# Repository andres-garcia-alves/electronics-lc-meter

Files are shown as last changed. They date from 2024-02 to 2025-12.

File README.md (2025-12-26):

# LC Meter v2.0

A Capacimeter + Inductometer based on Arduino Nano.  
Capacitor measurement with 3 working modes: accuracy (slow), balanced and speed.  

Case 3D model included ;-)

This proyect was inspired on video [Medidor de Bobinas/Inductores y Capacitores con Arduino y Display LCD](https://www.youtube.com/watch?v=hMa-AWyuxaA) (spanish) from [Electgpl](https://www.youtube.com/@electgpl) YouTube channel.

&nbsp;

This project use the following electronic components:
- 1 x Arduino Nano v3.0
- 1 x LCD Display 16x2
- 1 x LCD Display I2C Module
- 1 x LM358 Operational Amplifier
- 1 x Capacitor 1uF
- 1 x Switch Button (2 positions)
- 3 x Push Button
- 1 x 220 ohm resistor
- 1 x 470 ohm resistor
- 1 x 10K ohm resistor
- 1 x 100K ohm resistor
- 1 x 1M ohm resistor
- 14 x pin-header 90 degress
- 2 x Bornier x2 (optional)
- 1 x DC conector (optional power 5-12V)
- 2 x Alligator clip conector (optional external measurement)
- wires

&nbsp;

### Screenshots

| Diagram - Schematics | Diagram - PCB |
|---|---|
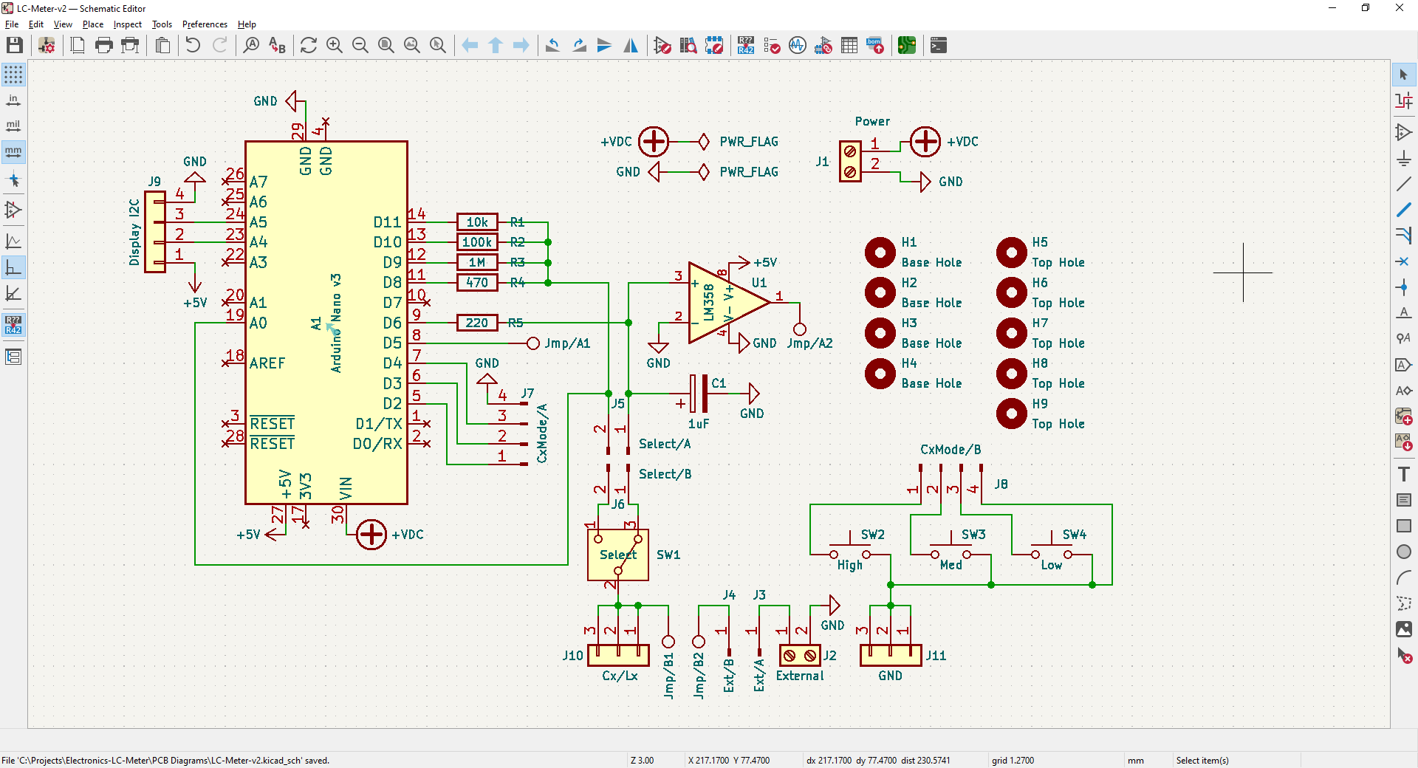
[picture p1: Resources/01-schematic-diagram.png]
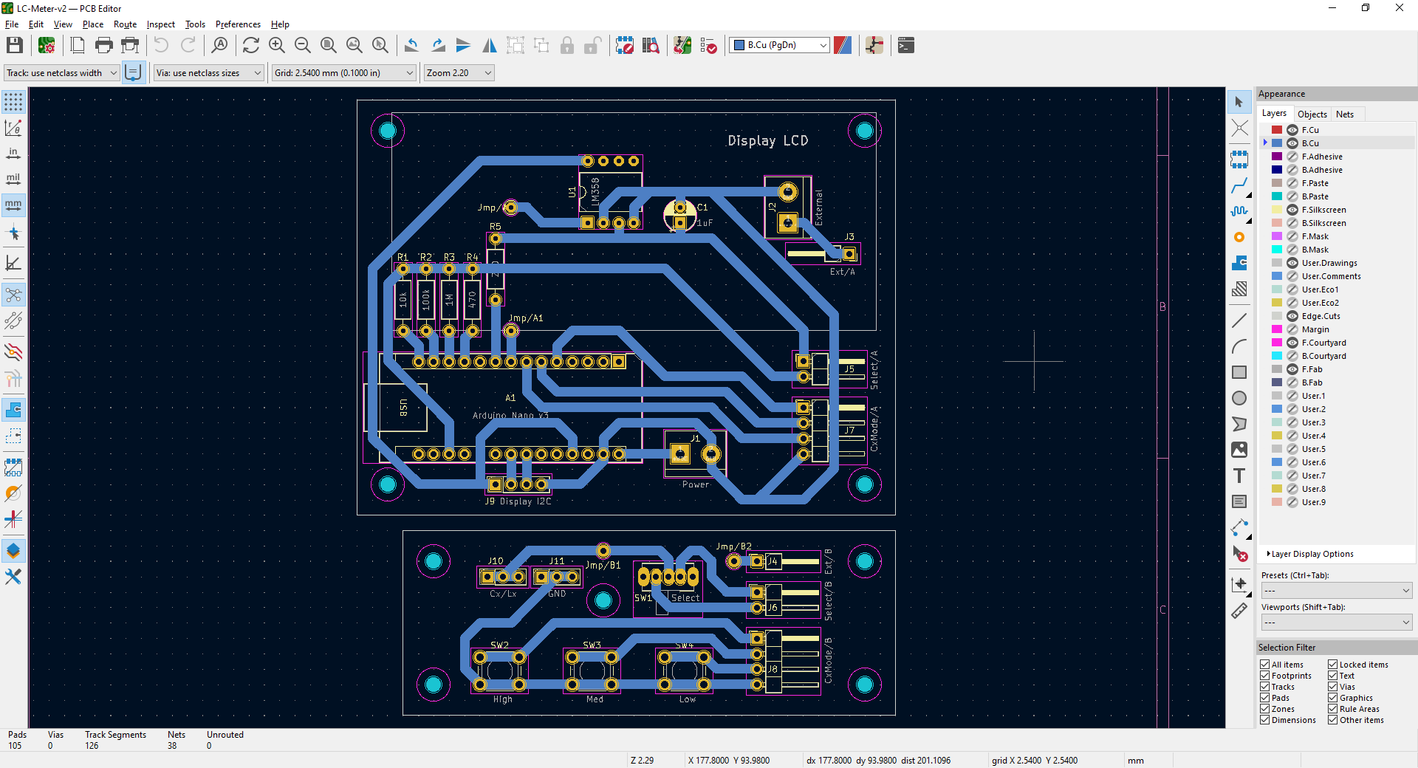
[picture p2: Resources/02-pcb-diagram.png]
|  |  |

| Diagram - PCB Render | Diagram - PCB Render |
|---|---|
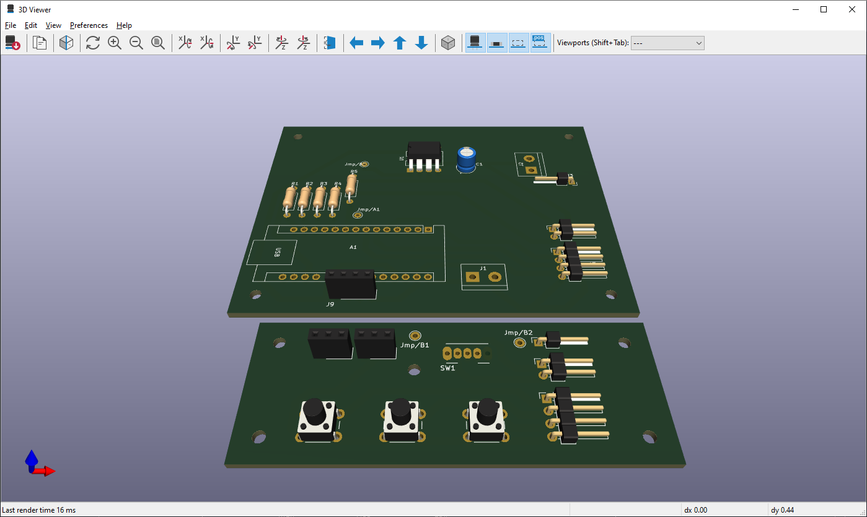
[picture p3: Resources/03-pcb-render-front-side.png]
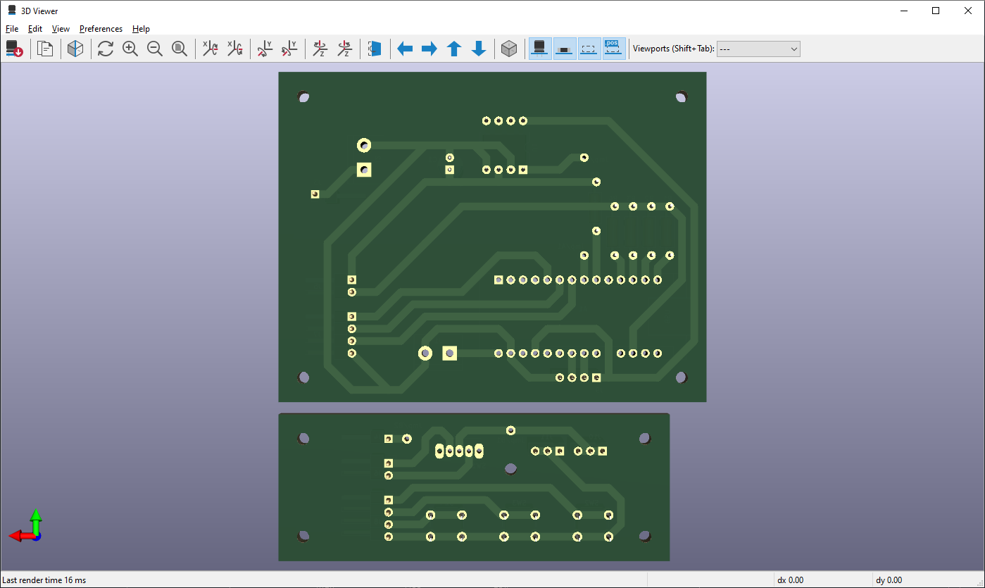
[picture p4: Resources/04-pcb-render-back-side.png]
|  |  |

| Prototype | Prototype |
|---|---|
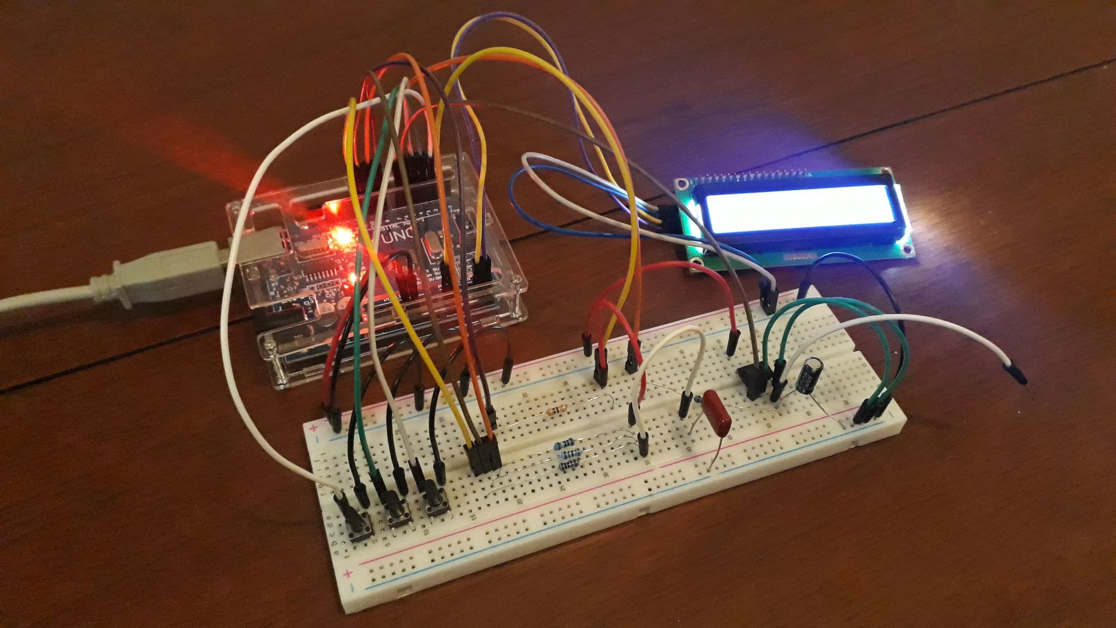
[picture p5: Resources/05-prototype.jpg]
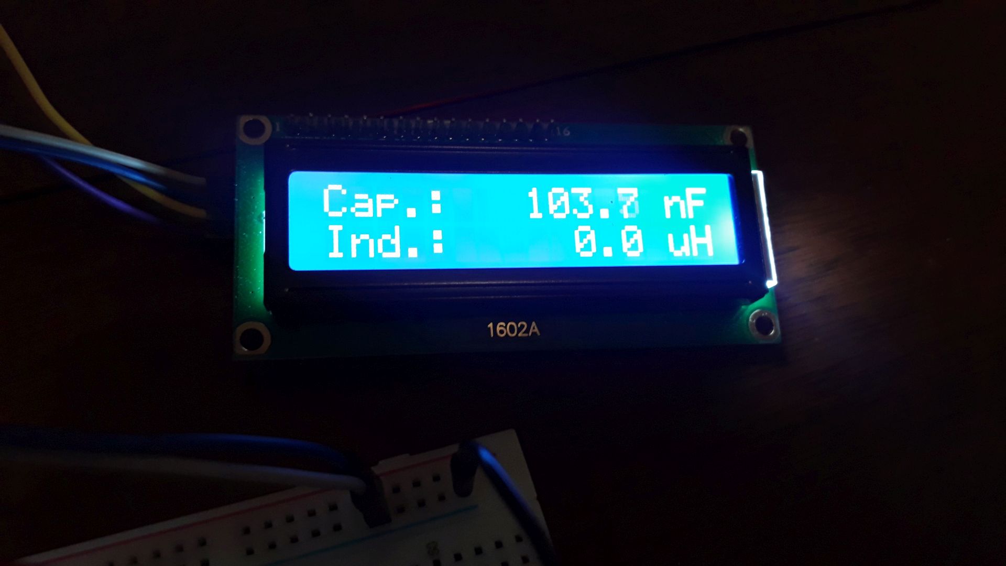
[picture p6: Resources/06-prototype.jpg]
|  |  |

| PCB Manufacturing | Project Assembly |
|---|---|
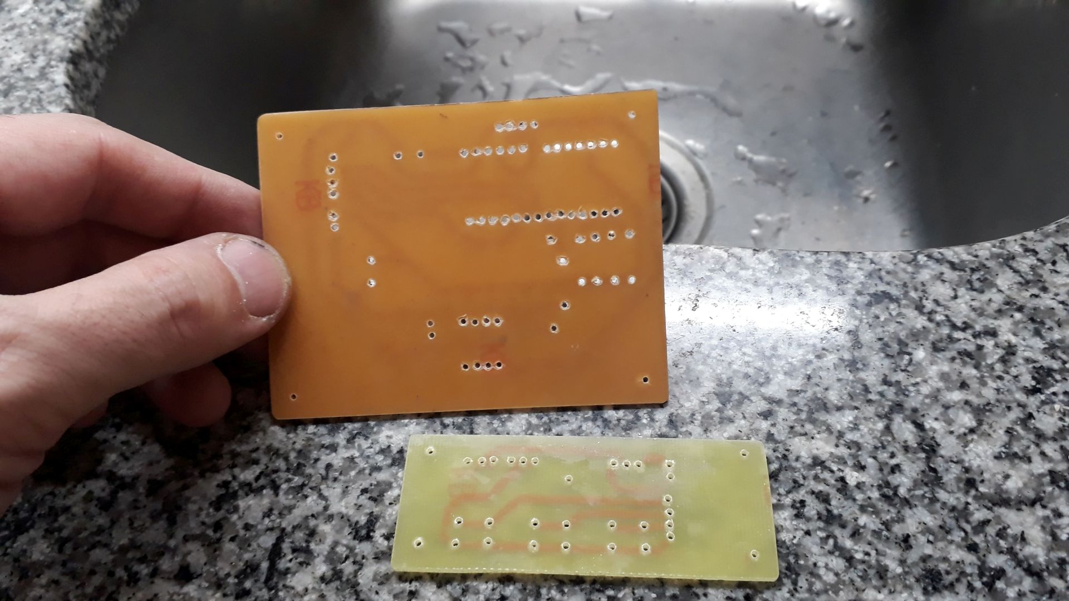
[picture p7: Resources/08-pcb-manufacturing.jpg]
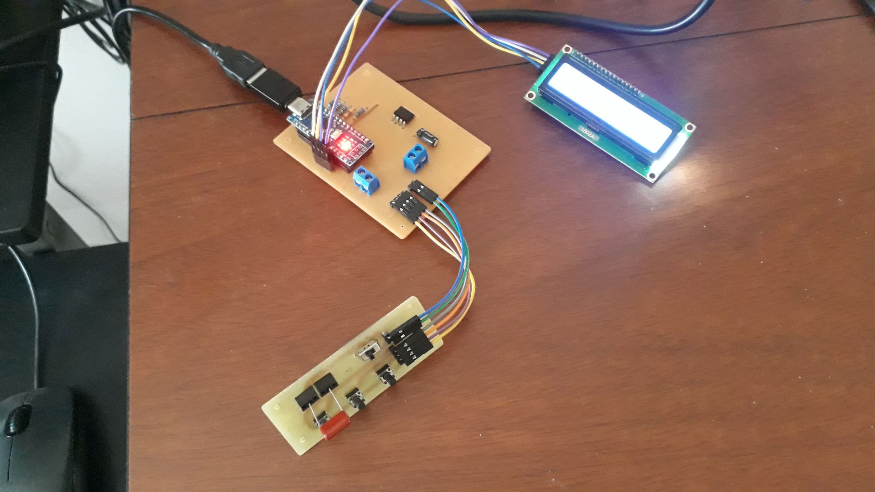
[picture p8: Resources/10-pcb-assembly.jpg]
|  |  |

| PCB Assembly | PCB Assembly |
|---|---|
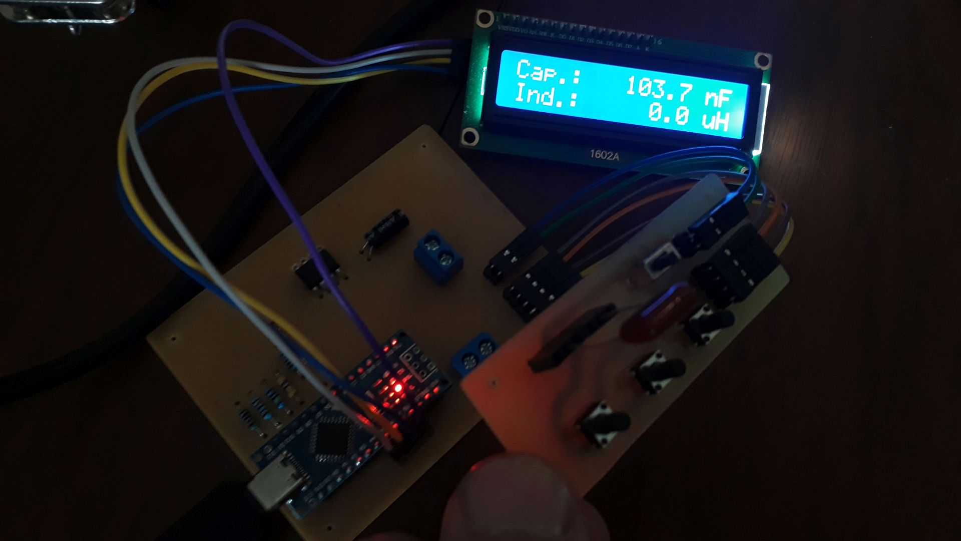
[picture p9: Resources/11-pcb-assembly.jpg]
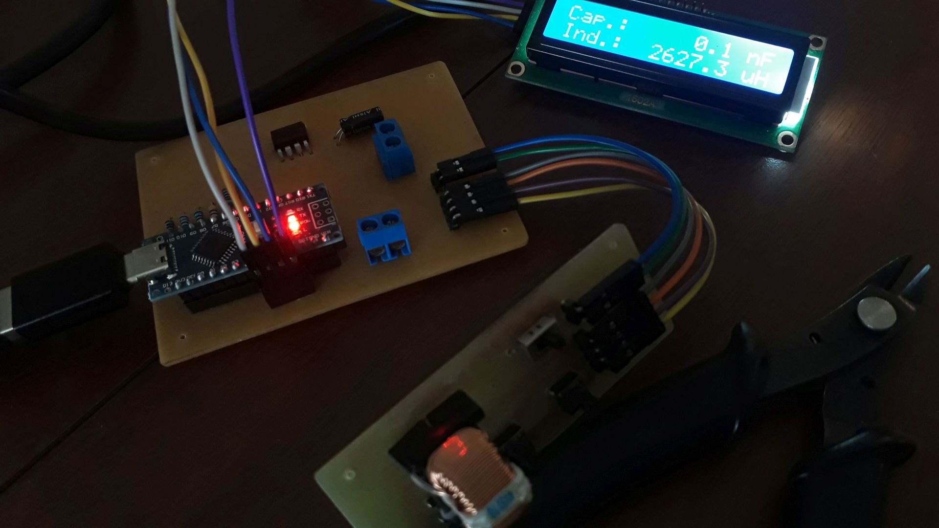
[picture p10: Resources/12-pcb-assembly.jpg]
|  |  |

| Case 3D model | Project Final |
|---|---|
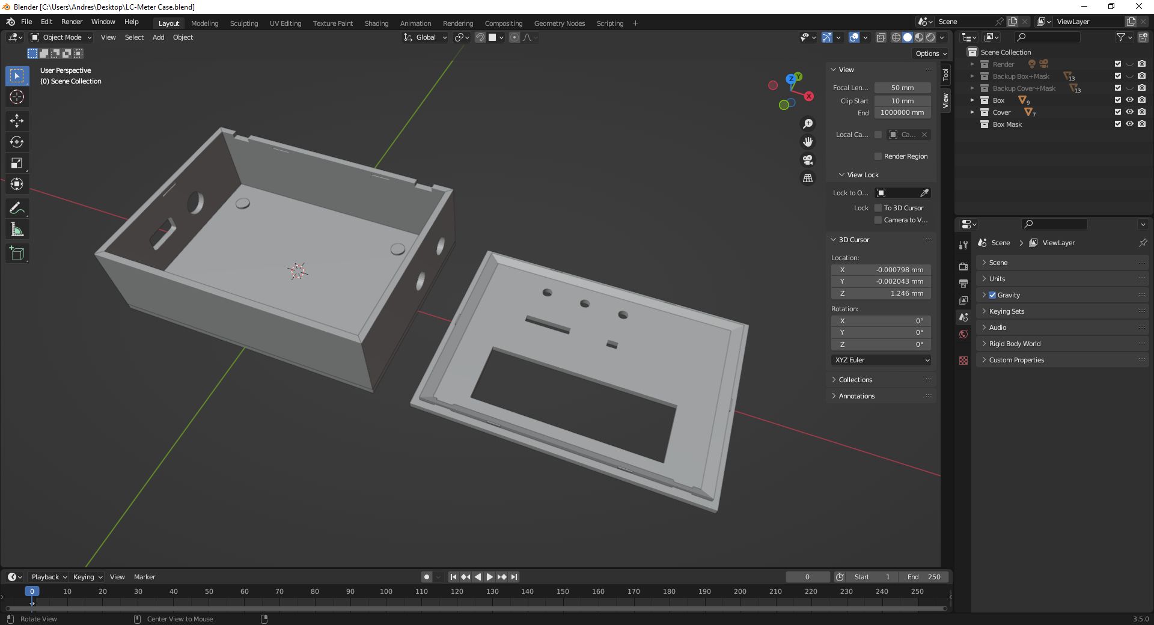
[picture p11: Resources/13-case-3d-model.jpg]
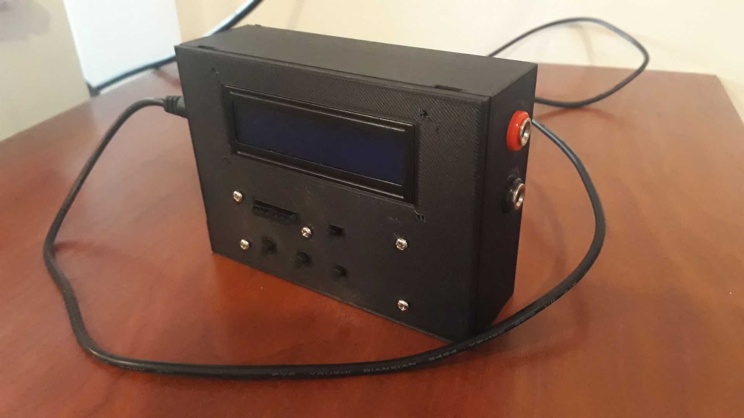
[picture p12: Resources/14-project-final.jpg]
|  |  |

| Capacimeter (YouTube video) | Inductometer (YouTube video) |
|---|---|
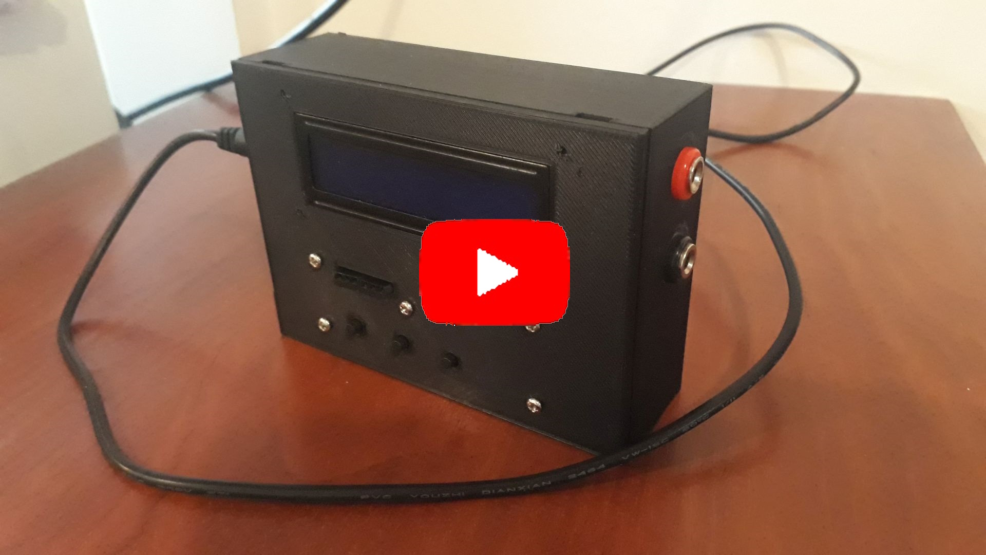
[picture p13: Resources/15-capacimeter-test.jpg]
(https://youtu.be/5dKCbQqo9p4)
|  | (https://youtu.be/Jn29TbQ0DK8) |

See 'Rescources' sub-folder for more pictures & videos of the project.

&nbsp;

### Version History

v1.0 (2024.03.02) - Initial release.  
v1.1 (2024.03.03) - Adding case 3D model.  
v1.2 (2024.03.09) - Pin position & component annotations improvements.  
v1.3 (2025.12.20) - Update project structure.  
v1.4 (2025.12.26) - Adding 'Stickers' folder.  

&nbsp;

This source code is licensed under GPL v3.0  
Please send me your feedback about this project: andres.garcia.alves@gmail.com

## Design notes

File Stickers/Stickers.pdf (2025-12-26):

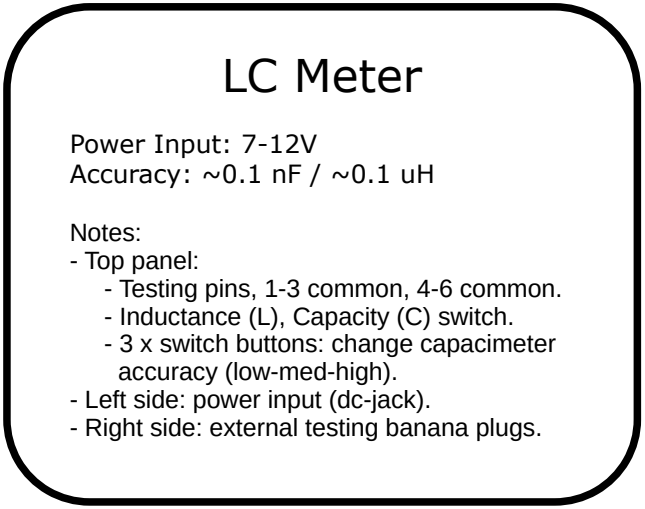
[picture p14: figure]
LC Meter; Notes: - Top panel: - Testing pins, 1-3 common, 4-6 common. - Inductance (L), Capacity (C) switch.; accuracy (low-med-high). - Left side: power input (dc-jack).; Power Input: 7-12V Accuracy: ~0.1 nF / ~0.1 uH

- 3 x switch buttons: change capacimeter
- Right side: external testing banana plugs.

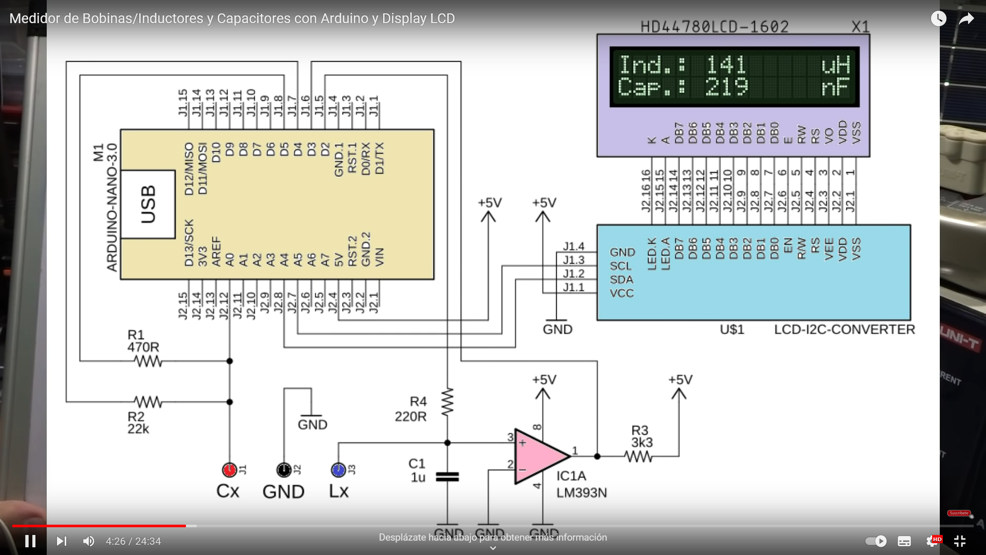
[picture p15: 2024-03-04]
Documentation/Schematic Diagram (original).png

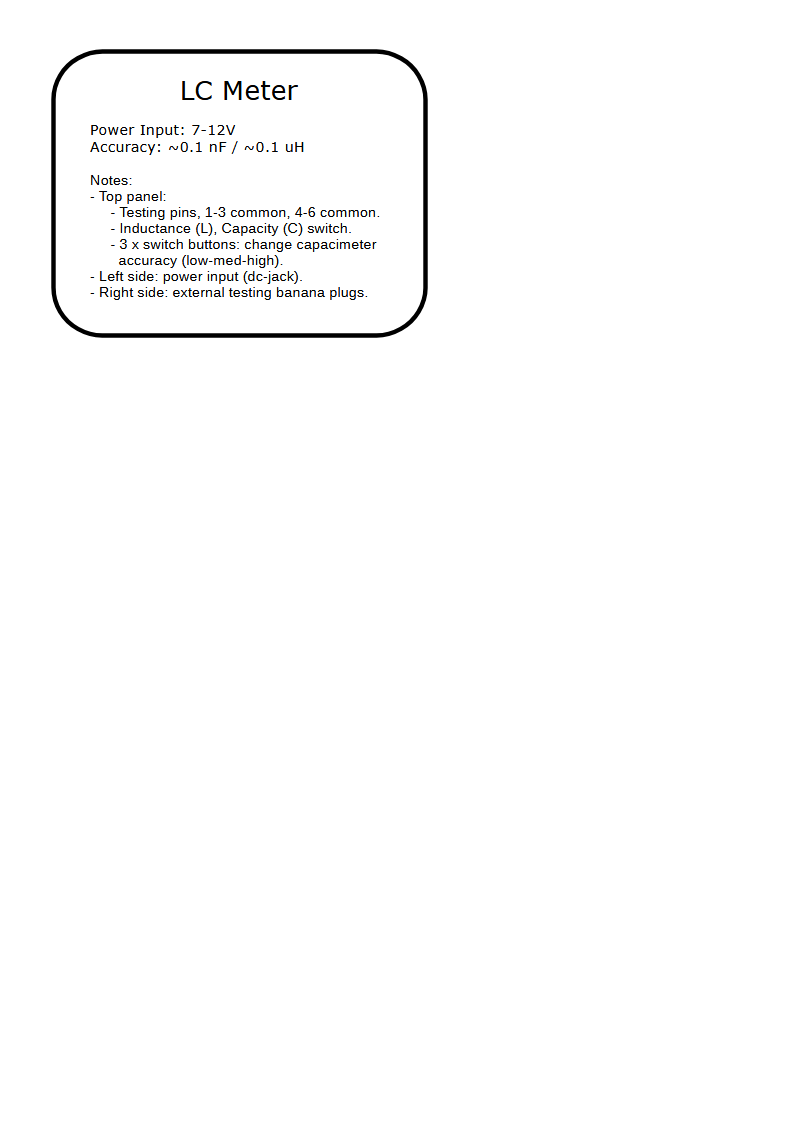
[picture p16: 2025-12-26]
Stickers/Stickers.png

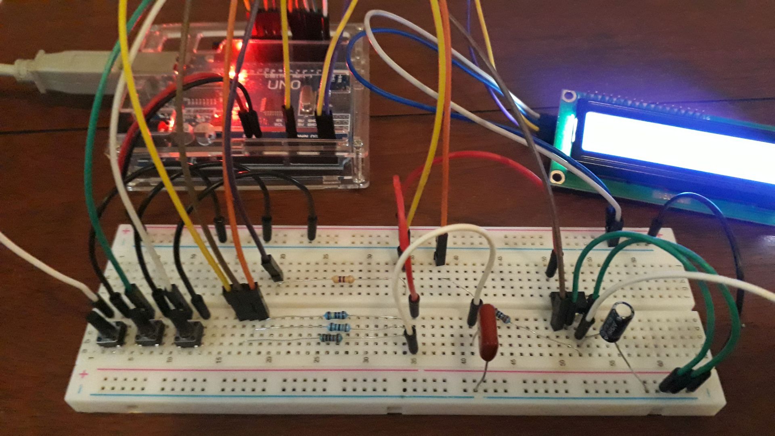
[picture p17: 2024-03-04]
Resources/07-prototype.jpg

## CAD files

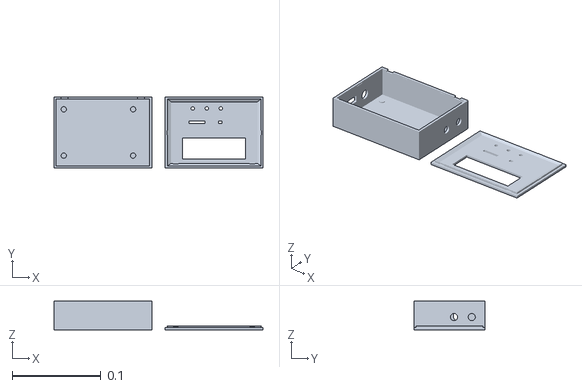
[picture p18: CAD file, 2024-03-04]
3D Model/Case 110x80x35mm.stl
0.235 x 0.0801 x 0.0325

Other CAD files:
3D Model/Case 110x80x35mm.blend

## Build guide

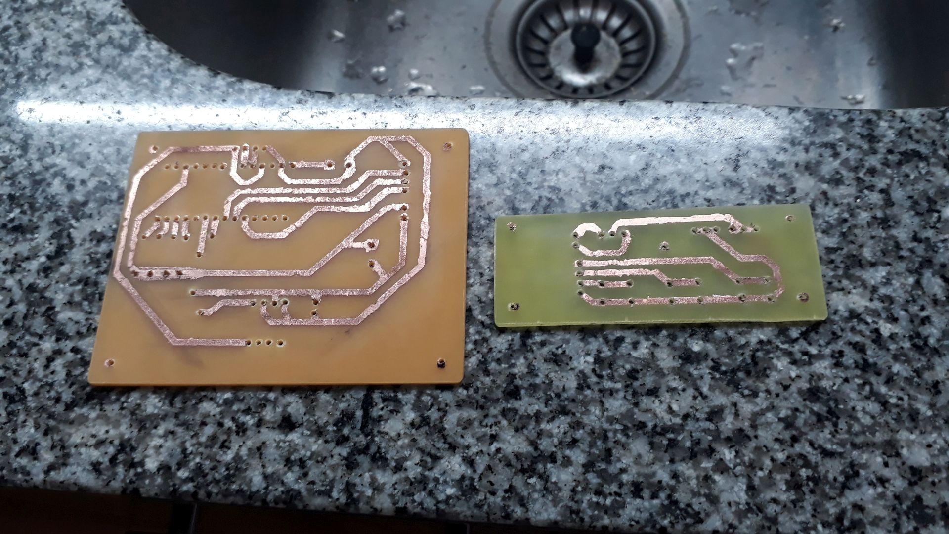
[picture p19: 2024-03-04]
Resources/09-pcb-manufacturing.jpg

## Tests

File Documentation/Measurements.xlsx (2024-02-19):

Tipo | Cap. Nominal | LC Meter | LC Meter | LC Meter | Multimetro Barovo
 |  | 21.8 kOhm (+/- 5 nF) | 46.8 kOhm (+/- 2 nF) | 100.3 kOhm (+/- 1 nF) | MUL9205A, máx 200 uF
Electrolitico | 470 uF | 436 uF | 440 uF | N/A | N/D
Electrolitico | 330 uF | 321 uF | 323 uF | N/A | N/D
Electrolitico | 100 uF | 97/98 uF | 99 uF | 99 uF | 104.2 uF
Electrolitico | 10 uF | 9 uF | 10 uF | 10 uF | 9.7 uF
Electrolitico | 4.7 uF | 5 uF | 5 uF | 5 uF | 4.6 uF
Electrolitico | 1 uF | 1 uF | 1 uF | 1 uF | 1 uF
Poliester | 220 nF | 228/229 nF | 225 nF | 223 nF | 224 nF
Poliester | 100 nF | 107 nF | 107 nF | 105 nF | 105.5 nF
Ceramico | 330 nF | 356 nF | 350/352 nF | 362 nF | 333 nF
Ceramico | 100 nF | 91/92 nF | 91 nF | 93 nF | 81.1 nF
Ceramico | 10 nF | 26 nF | 22 nF | 20 nF | 18.6 nF
Ceramico | 22 pF | N/D | N/D | N/D | N/D

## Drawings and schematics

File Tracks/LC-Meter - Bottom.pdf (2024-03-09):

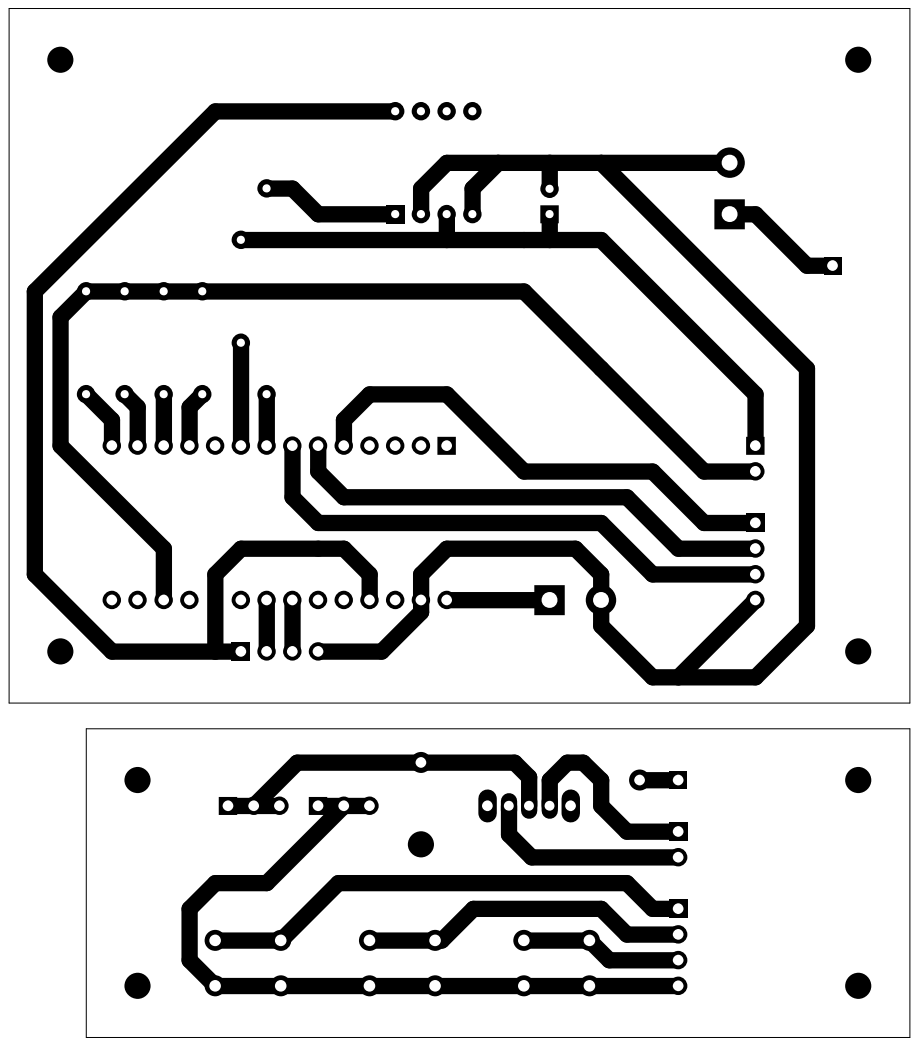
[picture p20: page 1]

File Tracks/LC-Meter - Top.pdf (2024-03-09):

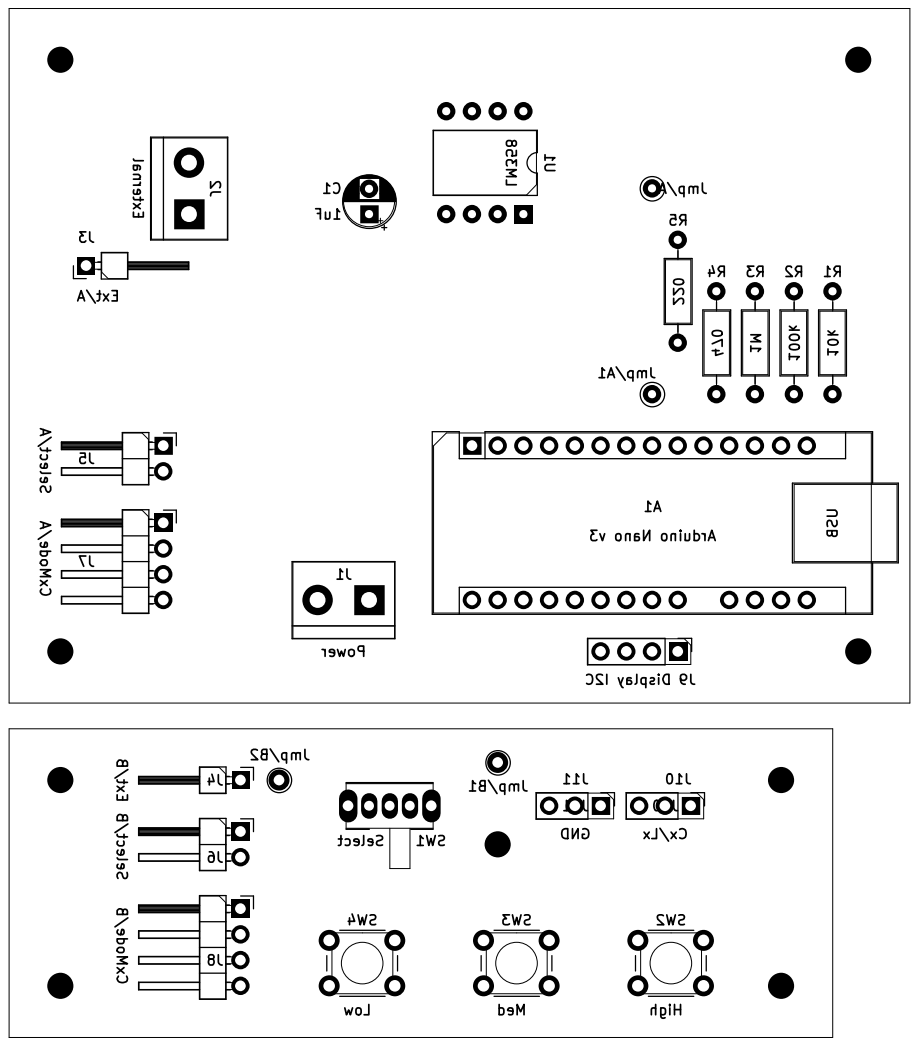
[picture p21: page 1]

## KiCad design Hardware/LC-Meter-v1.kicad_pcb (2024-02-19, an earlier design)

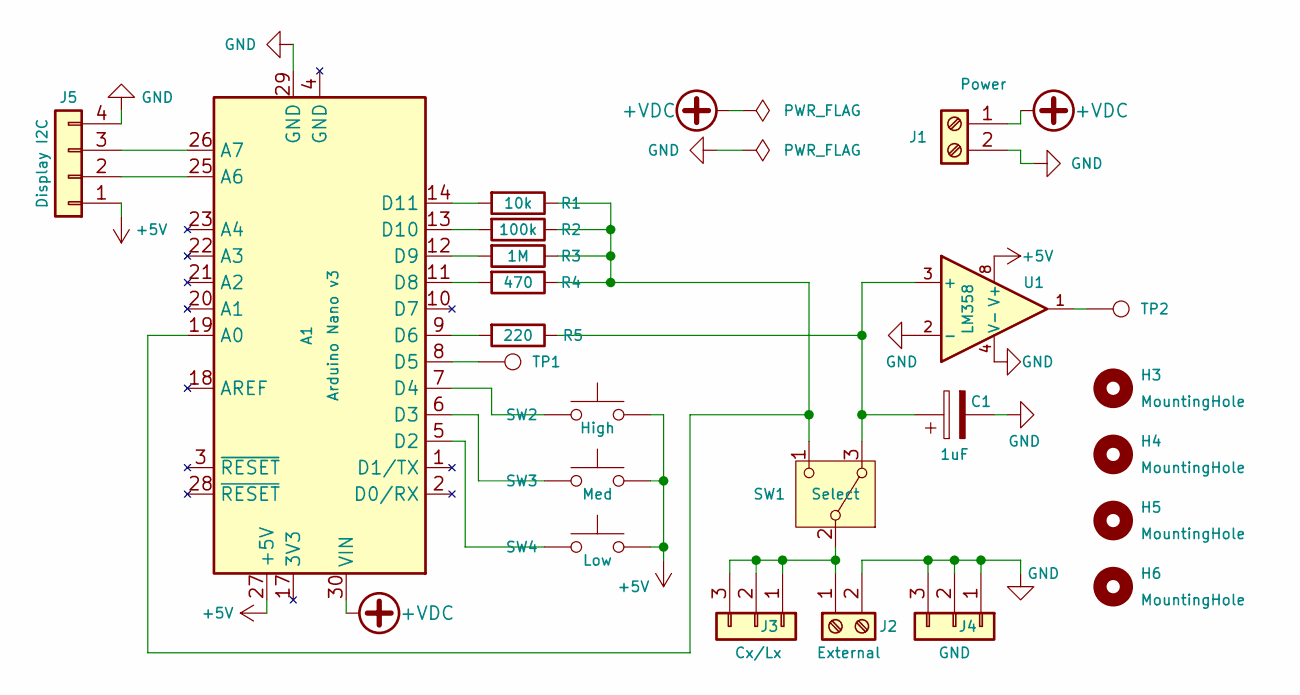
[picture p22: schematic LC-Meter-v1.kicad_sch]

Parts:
A1: Arduino Nano v3; Arduino_Nano
C1: 1uF; CP_Radial_D5.0mm_P2.50mm
H3, H4, H5, H6: MountingHole; MountingHole_2.5mm
J1: Power; TerminalBlock_bornier-2_P5.08mm
J2: External; TerminalBlock_bornier-2_P5.08mm
J3: Cx/Lx; PinSocket_1x03_P2.54mm_Vertical
J4: GND; PinSocket_1x03_P2.54mm_Vertical
J5: Display I2C; PinSocket_1x04_P2.54mm_Vertical
R1: 10k; R_Axial_DIN0207_L6.3mm_D2.5mm_P10.16mm_Horizontal
R2: 100k; R_Axial_DIN0207_L6.3mm_D2.5mm_P10.16mm_Horizontal
R3: 1M; R_Axial_DIN0207_L6.3mm_D2.5mm_P10.16mm_Horizontal
R4: 470; R_Axial_DIN0207_L6.3mm_D2.5mm_P10.16mm_Horizontal
R5: 220; R_Axial_DIN0207_L6.3mm_D2.5mm_P10.16mm_Horizontal
SW1: Select; SW_CuK_OS102011MA1QN1_SPDT_Angled
SW2: High; SW_PUSH_6mm_H7.3mm
SW3: Med; SW_PUSH_6mm_H7.3mm
SW4: Low; SW_PUSH_6mm_H7.3mm
TP1, TP2: Bridge; TestPoint_THTPad_D2.0mm_Drill1.0mm
U1: LM358; DIP-8_W10.16mm

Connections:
+5V: A1.27 (+5V), J5.1, SW2.2, SW3.2, SW4.2, U1.8 (V+)
+VDC: A1.30 (VIN), J1.1
GND: A1.29 (GND), C1.2, J1.2, J2.2, J4.1, J4.2, J4.3, J5.4, U1.2 (-), U1.4 (V-)
unnamed: A1.19 (A0), R1.1, R2.1, R3.1, R4.1, SW1.1 (C)
unnamed: A1.25 (A6), J5.2
unnamed: A1.26 (A7), J5.3
unnamed: A1.5 (D2), SW4.1
unnamed: A1.6 (D3), SW3.1
unnamed: A1.7 (D4), SW2.1
unnamed: A1.8 (D5), TP1.1
unnamed: A1.9 (D6), R5.2
unnamed: A1.11 (D8), R4.2
unnamed: A1.12 (D9), R3.2
unnamed: A1.13 (D10), R2.2
unnamed: A1.14 (D11), R1.2
unnamed: J2.1, J3.1, J3.2, J3.3, SW1.2 (B)
unnamed: C1.1, R5.1, SW1.3 (A), U1.3 (+)
unnamed: TP2.1, U1.1

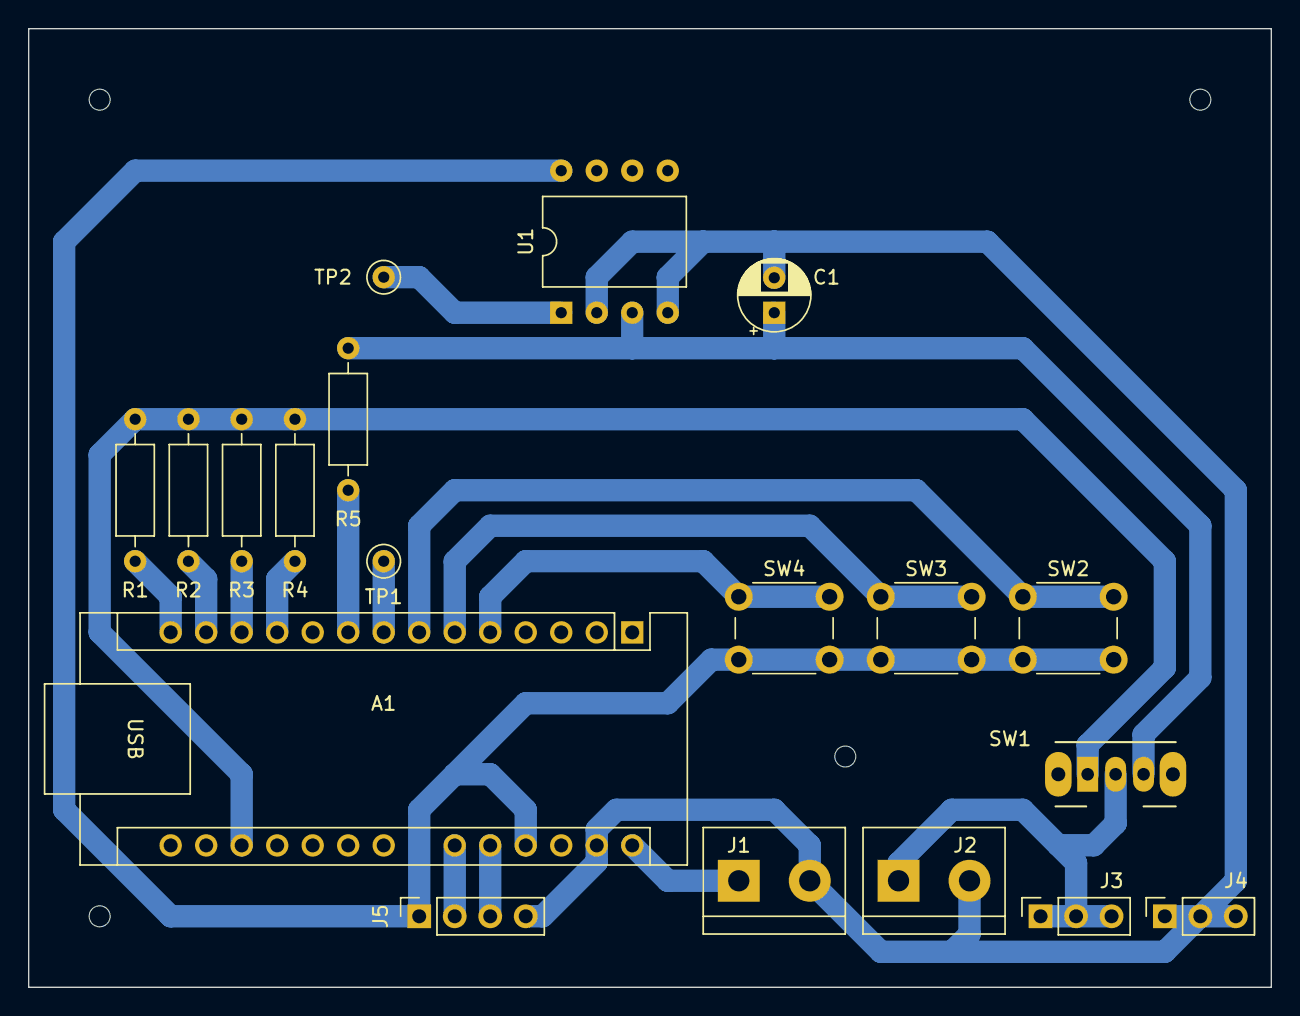
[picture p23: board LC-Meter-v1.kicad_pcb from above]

Board: 2 copper layers, 88.9 x 68.6 mm, 23 parts (0 on the bottom side), 18 nets.

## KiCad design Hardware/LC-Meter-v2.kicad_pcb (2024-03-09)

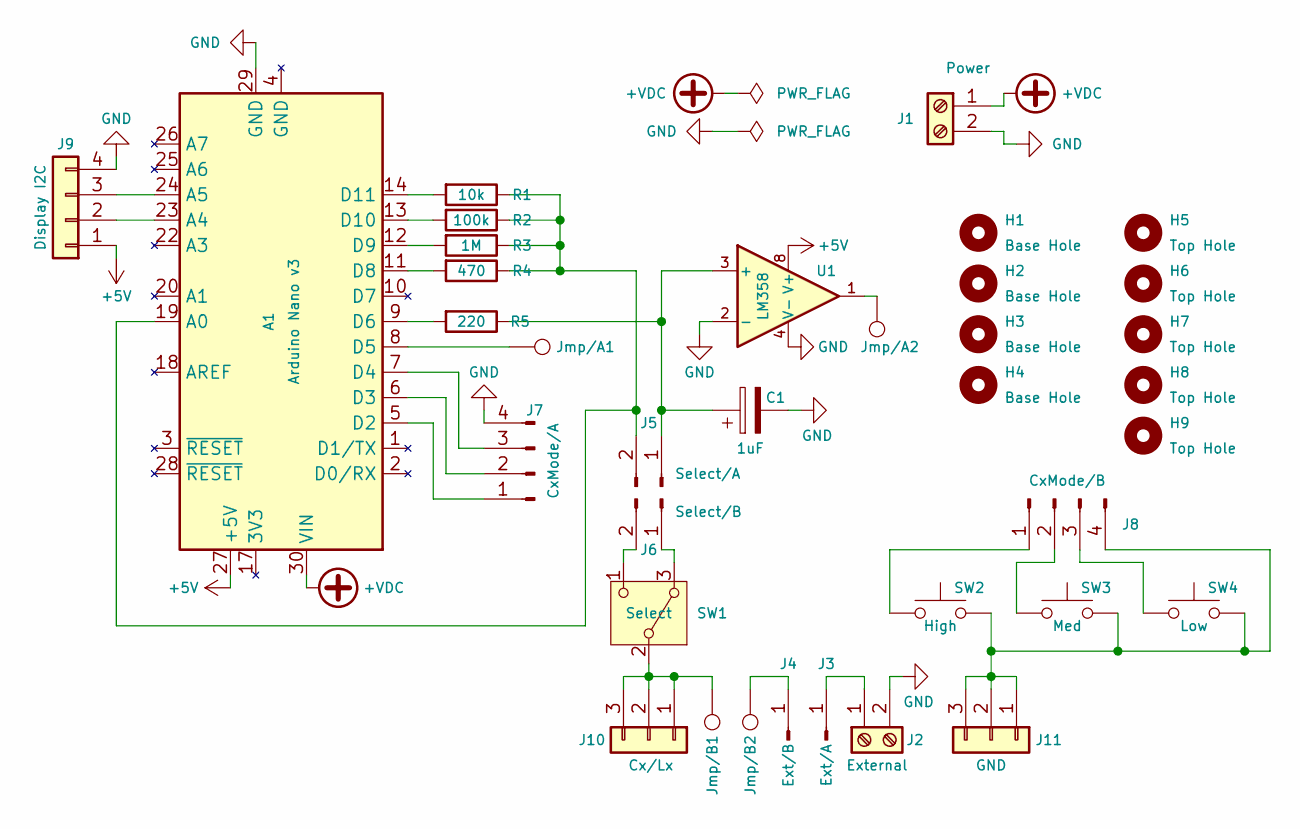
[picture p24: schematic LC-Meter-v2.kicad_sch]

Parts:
A1: Arduino Nano v3; Arduino_Nano
C1: 1uF; CP_Radial_D5.0mm_P2.50mm
H1, H2, H3, H4: Base Hole; MountingHole_2.5mm
H5, H6, H7, H8, H9: Top Hole; MountingHole_2.5mm
J1: Power; TerminalBlock_bornier-2_P5.08mm
J2: External; TerminalBlock_bornier-2_P5.08mm
J3: Ext/A; PinHeader_1x01_P2.54mm_Horizontal
J4: Ext/B; PinHeader_1x01_P2.54mm_Horizontal
J5: Select/A; PinHeader_1x02_P2.54mm_Horizontal
J6: Select/B; PinHeader_1x02_P2.54mm_Horizontal
J7: CxMode/A; PinHeader_1x04_P2.54mm_Horizontal
J8: CxMode/B; PinHeader_1x04_P2.54mm_Horizontal
J9: Display I2C; PinSocket_1x04_P2.54mm_Vertical
J10: Cx/Lx; PinSocket_1x03_P2.54mm_Vertical
J11: GND; PinSocket_1x03_P2.54mm_Vertical
Jmp/A1, Jmp/A2: Bridge; TestPoint_THTPad_D2.0mm_Drill1.0mm
Jmp/B1, Jmp/B2: Bridge; TestPoint_THTPad_D2.0mm_Drill1.0mm
R1: 10k; R_Axial_DIN0207_L6.3mm_D2.5mm_P10.16mm_Horizontal
R2: 100k; R_Axial_DIN0207_L6.3mm_D2.5mm_P10.16mm_Horizontal
R3: 1M; R_Axial_DIN0207_L6.3mm_D2.5mm_P10.16mm_Horizontal
R4: 470; R_Axial_DIN0207_L6.3mm_D2.5mm_P10.16mm_Horizontal
R5: 220; R_Axial_DIN0207_L6.3mm_D2.5mm_P10.16mm_Horizontal
SW1: Select; SW_CuK_OS102011MA1QN1_SPDT_Angled
SW2: High; SW_PUSH_6mm_H7.3mm
SW3: Med; SW_PUSH_6mm_H7.3mm
SW4: Low; SW_PUSH_6mm_H7.3mm
U1: LM358; DIP-8_W10.16mm

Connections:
+5V: A1.27 (+5V), J9.1, U1.8 (V+)
+VDC: A1.30 (VIN), J1.1
GND: A1.29 (GND), C1.2, J1.2, J2.2, J7.4, J9.4, U1.2 (-), U1.4 (V-)
unnamed: A1.19 (A0), J5.2, R1.1, R2.1, R3.1, R4.1
unnamed: A1.23 (A4), J9.2
unnamed: A1.24 (A5), J9.3
unnamed: A1.5 (D2), J7.1
unnamed: A1.6 (D3), J7.2
unnamed: A1.7 (D4), J7.3
unnamed: A1.8 (D5), Jmp/A1.1
unnamed: A1.9 (D6), R5.2
unnamed: A1.11 (D8), R4.2
unnamed: A1.12 (D9), R3.2
unnamed: A1.13 (D10), R2.2
unnamed: A1.14 (D11), R1.2
unnamed: J2.1, J3.1
unnamed: J4.1, Jmp/B2.1
unnamed: C1.1, J5.1, R5.1, U1.3 (+)
unnamed: J6.1, SW1.3 (A)
unnamed: J6.2, SW1.1 (C)
unnamed: J8.1, SW2.1
unnamed: J8.2, SW3.1
unnamed: J8.3, SW4.1
unnamed: J10.1, J10.2, J10.3, Jmp/B1.1, SW1.2 (B)
unnamed: J8.4, J11.1, J11.2, J11.3, SW2.2, SW3.2, SW4.2
unnamed: Jmp/A2.1, U1.1

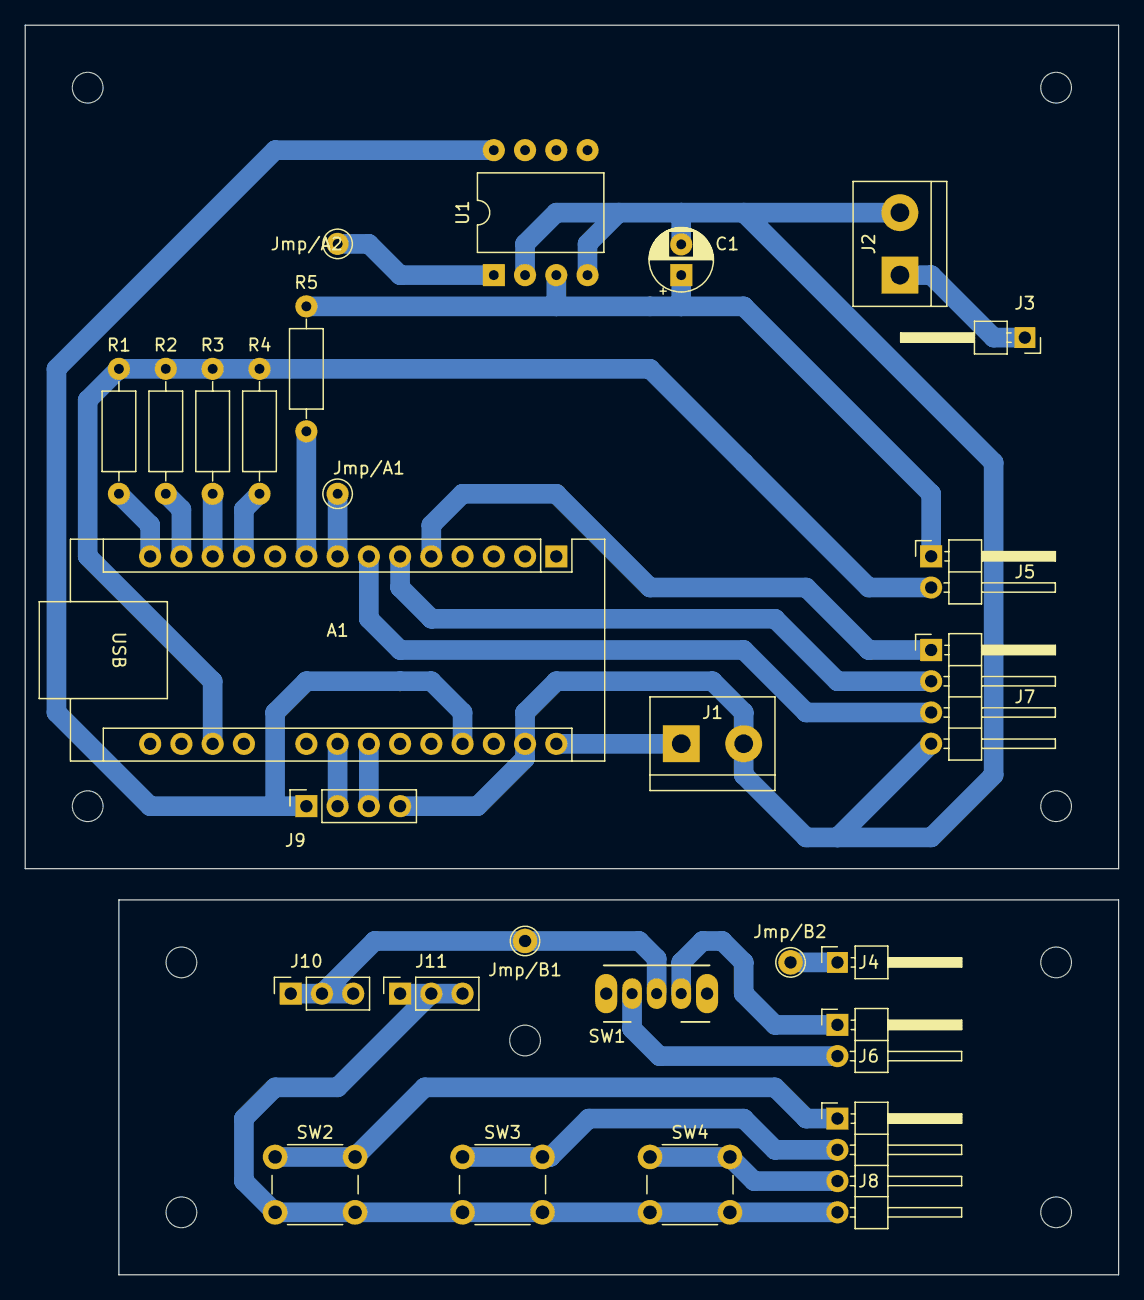
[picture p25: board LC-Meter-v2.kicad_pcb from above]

Board: 2 copper layers, 88.9 x 101.6 mm, 36 parts (0 on the bottom side), 26 nets.

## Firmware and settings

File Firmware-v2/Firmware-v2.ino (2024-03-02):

#include "Definitions.h"
#include "Display_LCD.h"
#include "Measurements.h"

void setup()
{
  setupLCD();
  defaultPinout(true);
  setCapacimeterMode(Med);
  showIntro(2000);

  #ifdef DEBUG
  Serial.begin(9600);
  #endif
}

void loop()
{
  CapacimeterMode mode = checkInput();

  if (mode != None) {
    setCapacimeterMode(mode);
    showCapacitanceMode();
    defaultPinout(false);
  }

  showCapacitance();
  showInductance();

  delay(50);
}

CapacimeterMode checkInput()
{
  byte value = 0;

  if      (digitalRead(PIN_BTN_CX_LOW) == LOW)   { value = Low; }
  else if (digitalRead(PIN_BTN_CX_MED) == LOW)   { value = Med; }
  else if (digitalRead(PIN_BTN_CX_HIGH) == LOW)  { value = High; }

  delay(75);

  if      (value == Low && digitalRead(PIN_BTN_CX_LOW) == LOW)    { return Low; }
  else if (value == Med && digitalRead(PIN_BTN_CX_MED) == LOW)    { return Med; }
  else if (value == High && digitalRead(PIN_BTN_CX_HIGH) == LOW)  { return High; }
  else                                                            { return None; }
}

void showIntro(unsigned int wait)
{
  printLCD(0, LCD_ROW_0, "    LC Meter    ");
  printLCD(0, LCD_ROW_1, "                ");
  delay(wait);
}

void showCapacitance()
{
  float capacitance = getCapacitance();

  char value[MEASURE_LEN];
  (capacitance < 1000) ? dtostrf(capacitance, MEASURE_LEN, 1, value) : dtostrf(capacitance / 1000.0, MEASURE_LEN, 1, value);
  String unit = (capacitance < 1000) ? " nF" : " uF";

  printLCD(0, LCD_ROW_0, "Cap.: " + (String)value + unit);

  #ifdef DEBUG
  Serial.println("Cap.: " + (String)value + unit);
  delay(500);
  #endif
}

void showInductance()
{
  float inductance = getInductance();

  char value[MEASURE_LEN];
  dtostrf(inductance, MEASURE_LEN, 1, value);

  printLCD(0, LCD_ROW_1, "Ind.: " + (String)value + " uH");

  #ifdef DEBUG
  Serial.println("Ind.: " + (String)value + " uH");
  delay(500);
  #endif
}

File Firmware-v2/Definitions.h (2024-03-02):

#ifndef DEFINITIONS_H
#define DEFINITIONS_H

#define PIN_BTN_CX_LOW      2
#define PIN_BTN_CX_MED      3
#define PIN_BTN_CX_HIGH     4

#define PIN_CAPACITOR_CHARGE_LOW    9
#define PIN_CAPACITOR_CHARGE_MED    10
#define PIN_CAPACITOR_CHARGE_HIGH   11
#define PIN_CAPACITOR_DISCHARGE     8
#define PIN_CAPACITOR_MEASURE       A0

#define PIN_INDUCTANCE_OUT  6
#define PIN_INDUCTANCE_IN   5

#define CX_RESISTOR_LOW     1017000.0   // Cx measure, load resistor 3 (Ohms)
#define CX_RESISTOR_MED     0099550.0   // Cx measure, load resistor 2 (Ohms)
#define CX_RESISTOR_HIGH    0010060.0   // Cx measure, load resistor 1 (Ohms)
#define CX_PARASITIC_LOW    00.2        // Cx parasitic capacity, accuracy mode
#define CX_PARASITIC_MED    01.1        // Cx parasitic capacity, balanced mode
#define CX_PARASITIC_HIGH   11.1        // Cx parasitic capacity, speed mode
#define LX_CAPACITOR        0.000001000 // Lx measure, parallel capacitor (nF)

#define LCD_ROW_0           0
#define LCD_ROW_1           1
#define MEASURE_LEN         7

#define DEBUG               false

// capacimeter mode: 1 = Low (pF), 2 = Med (nF), 3 = High (uF)
enum CapacimeterMode { None, Low, Med, High };


void defaultPinout(bool includeButtons)
{
  if (includeButtons) {
    pinMode(PIN_BTN_CX_LOW, INPUT_PULLUP);
    pinMode(PIN_BTN_CX_MED, INPUT_PULLUP);
    pinMode(PIN_BTN_CX_HIGH, INPUT_PULLUP);
  }

  // all pins to high-impedance
  pinMode(PIN_CAPACITOR_CHARGE_LOW, INPUT);
  pinMode(PIN_CAPACITOR_CHARGE_MED, INPUT);
  pinMode(PIN_CAPACITOR_CHARGE_HIGH, INPUT);
  pinMode(PIN_CAPACITOR_DISCHARGE, INPUT);
  pinMode(PIN_CAPACITOR_MEASURE, INPUT);

  pinMode(PIN_INDUCTANCE_OUT, INPUT);
  pinMode(PIN_INDUCTANCE_IN, INPUT);
}

#endif

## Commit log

2024-02-19 first release
    [LC-Meter-v1.kicad_pcb, LC-Meter-v1.kicad_sch, LC-Meter-v2.kicad_pcb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]
2024-03-04 adding case 3D model
    [Case 110x80x35mm.blend, Case 110x80x35mm.stl]
2024-03-09 pin position & component annotations improvements
    [Case 110x80x35mm.blend, LC-Meter-v2.kicad_pcb, LC-Meter-v2.kicad_sch]
2026-02-02 Update Tracks
    [LC-Meter-v1.kicad_pcb, LC-Meter-v1.kicad_sch, LC-Meter-v2.kicad_pcb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]
